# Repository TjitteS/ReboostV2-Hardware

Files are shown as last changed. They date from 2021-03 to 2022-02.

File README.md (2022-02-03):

# ReboostV2-Hardware
Hardware files for [OpenSmartEnergyConverter](https://github.com/TjitteS/OpenSmartEnergyConverter)

[Schematic](https://github.com/TjitteS/ReboostV2-Hardware/blob/main/Outputs/Reboost%20V0.2.1/Schematic%20Prints.PDF) and production files can be found in the output folder.

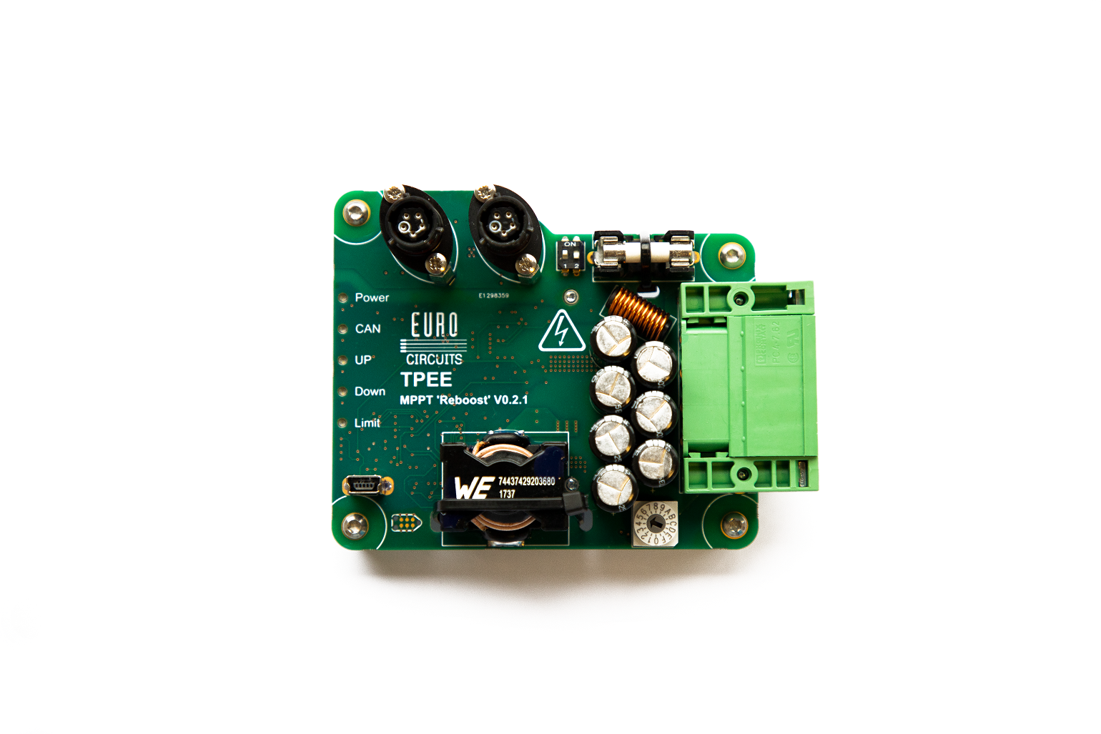
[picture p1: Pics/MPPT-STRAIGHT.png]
IMPPT


### Verison ###

The output folder contains two verison. the only major diference between the two versions is the CAN-bus connector that is used. V0.2.0 contains easy to source microfit connectors and is the recomended design.

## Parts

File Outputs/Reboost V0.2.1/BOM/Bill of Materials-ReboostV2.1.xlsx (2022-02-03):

Comment | Description | Designator | Footprint | Quantity
1nF | Capacitor, 1nF, 50V, X7R | C1_IHS, C1_ILS, C4_IHS, C4_ILS | C0603 | 4
100nF | Capacitor, 100nF, 50V, X7R | C2_IHS, C2_ILS, C3_IHS, C3_ILS, C6, C9, C13, C15, C16, C17, C18, C20, C21, C31, C39, C42, C45, C51, C54, C59, C60, C61 | C0603 | 22
2.2uF | Capacitor, 2.2uF, 16V, X5R | C5, C7, C8, C12, C14, C19, C30, C40, C52, C56, C67 | C0603 | 11
15pF | Capacitor, 15pF, 50V, C0G / NP0 | C10, C11 | C0603 | 2
100uF | Aluminum Electrolytic Capacitor, 100uF, 100V | C22, C23, C24, C25, C26, C28, C34 | WCAP-ATUL_10x20x5x0.6 | 7
100nF | Capacitor, 100nF, 100V, X7R | C27, C29, C35, C43 | C-0805 | 4
1uF | Capacitor, 1uF, 100V, X7R | C32, C33, C36, C37, C38, C44, C64 | C-1206 | 7
10uF | Capacitor, 10uF, 10V, X7R | C41, C46, C53, C58, C62, C65, C66 | C-0805 | 7
10nF | Capacitor, 10nF, 50V, X7R | C47, C55, C57 | C0603 | 3
4.7uF | Capacitor, 4.7uF, 16V, X7R | C48, C49, C50 | C-0805 | 3
SP0502BAHTG | Diode TVS Dual, Vrwm: 5.5V Vc: 8V | D1 | SOT23 | 1
SS110L | Diode Schottky, Vrrm: 100V, If: 1A, Vf: 0.9V | D2, D3 | SUB-SMA | 2
HMHA2801 | Optocoupler, Vout:80V, Iin:0.01A | D4 | FSOP4 | 1
MMSD701T1G | Diode Schottky, Vrrm: 70V, If: 0.2A, Vf: 0.5V | D5, D6, D7 | SOD123 - B | 3
SMAJ58A | Diode TVS, Vrwm: 58V, Vbr: 71.2V, Vc: 93.6V, Ippm: 4.3A | D8 | SMA | 1
Fuse Holder | Fuse, Holder, 10A, 250V, T:-40°C +85°C | F1 | Fuse5x20TH | 1
Header 1x4 | Header, Close Horizontal, 1x4, Male, 7.62mm, TH | J1 | PC 4/ 4-G-7,62 | 1
USB-B-MINI-VERT | Connector, Usb B Mini, Vertical, TH, WR-COM | J2 | USB-B-MINI-VERT | 1
CAN_BUS-Deutsch_ASL206-05SD-HE |  | J8, J9 | ASL206-05SD-HE | 2
2uH, 10A | WE-SD Rod Core Choke, 2uH, 10A | L1 | 744710210 | 1
68uH, 11.2A | WE-HCF SMT High Current Inductor, size 2920, 68uH, 11.2A, 24.42mOhm | L2 | WE-HCF_2920 | 1
150uH 0.42A | 150UH, 30%, 0.42A | L3, L4, L5 | WE-TPC 4828, MH | 3
800Ohm | WE-CNSW SMT Common Mode Line Filter, size 1812, 800Ohm, 1A, 60V | L6 | WE-CNSW_1812 | 1
90Ohm | WE-CNSW SMT Common Mode Line Filter, size 0805, 90Ohm, 0.37A, 50V | L7_VHS, L7_VLS | WE-CNSW_0805 | 2
GRN | LED, Reverse Mount, Cylindrical, Green | LED1, LED4, LED5 | WL-SMRW_1206 cylindrical_Reverse use | 3
RED | LED, Reverse Mount, Cylindrical, Red | LED2, LED3 | WL-SMRW_1206 cylindrical_Reverse use | 2
M2.5x2mm | WA-SMSI SMT Steel Spacer, M2.5 Thread Internal, OD 5.1mm, M2.5x2mm | MP1, MP2, MP3, MP4, MP5, MP6 | 9774020151 | 6
GS61008T | GAN TRANS E-MODE 100V 90A TOP SIDE COOL | Q1, Q2 | GS61008T | 2
MMBT5401LT1G | Transistor, PNP, Vce:-150V, Vcb:-160V, Veb:-5V, Ic:-0,5A, Hfe:60 to 240 | Q3 | SOT-23 | 1
330R | Resistor, 330R, 1%, 0.063W, 50V, 100PPM, 0603 | R1, R2, R3, R4, R5 | 0603 | 5
0.005R | Resistor, 0.005R, 1%, 2W, 50PPM | R6_IHS, R6_ILS | 2512-L-4T | 2
1K | Resistor, 1K, 1%, 0.063W, 50V, 100PPM, 0603 | R7_IHS, R7_ILS, R9_IHS, R9_ILS | 0603 | 4
47k | Resistor, 47K, 0.1%, 0.063W, 50V, 100PPM, 0603 | R8_IHS, R8_ILS, R10_IHS, R10_ILS, R35, R47 | 0603 | 6
10K | Resistor, 10K, 1%, 0.063W, 50V, 100PPM, 0603 | R11, R14, R15, R16, R17, R24, R32, R36, R42, R44, R45, R49_VHS, R49_VLS, R50 | 0603 | 14
120K | Resistor, 120K, 1%, 0.063W, 50V, 100PPM, 0603 | R12_VHS, R12_VLS | 0603 | 2
180K | Resistor, 180K, 1%, 0.063W, 50V, 100PPM, 0603 | R13_VHS, R13_VLS | 0603 | 2
100K | Resistor, 100K, 1%, 0.063W, 50V, 100PPM, 0603 | R18, R19, R28 | 0603 | 3
NTC-100K | NTC, 100K, 25°C, 0.5%, 0.210W, 0805 | R20, R21 | R0805 | 2
2R | Resistor, 2R, 5%, 0.1W, 75V, 200PPM, 0603 | R22, R27 | 0603 | 2
750K | Resistor, 750K, 1%, 0.063W, 50V, 100PPM, 0603 | R25, R34 | 0603 | 2
470K | Resistor, 470K, 1%, 0.063W, 50V, 100PPM, 0603 | R26 | 0603 | 1
470 | Resistor, 470, 1%, 0.063W, 50V, 100PPM, 0603 | R29 | 0603 | 1
20K | Resistor, 20K, 1%, 0.063W, 50V, 100PPM, 0603 | R30 | 0603 | 1
100R | Resistor, 100R, 1%, 0.063W, 50V, 200PPM, 0603 | R31 | 0603 | 1
130K | Resistor, 130K, 1%, 0.063W, 50V, 100PPM, 0603 | R33 | 0603 | 1
200K | Resistor, 200K, 1%, 0.063W, 50V, 100PPM, 0603, Resistor, 200K, 1%, 0.1W, 75V, 100PPM, 0603 | R37, R38, R40, R53 | 0603 | 4
0R | Resistor, 0R, 0.1%, 0.063W, 50V, 200PPM, 0603 | R39, R41 | 0603 | 2
12K | Resistor, 12K, 1%, 0.063W, 50V, 100PPM, 0603 | R48 | 0603 | 1
418127270902 | WS-DITV Small Compact THT Dip Switch, Raised Actuator, pitch 2.54mm, 2p | S1 | 418127270902 | 1
428527320916 | WS-ROTV THT Rotary Switch with Arrow Type Actuator, 10x10mm, 16 positions | S2 | 42852732091x_16p | 1
LTC6362 | Precision, Low Power Rail-to-Rail Input/Output Differential Op Amp | U1_IHS, U1_ILS | MSOP8 | 2
CP2104-F03-GM | USB to UART converter | U2 | QFN24 | 1
STM32G474 | ARM MCU, STM32 Family STM32G4 Series Microcontrollers, ARM Cortex-M4F, 32bit, 170 MHz, 512 KB | U3 | QFN48 | 1
74LVC2G08 | Dual 2-input AND gate | U4 | TSSOP8 | 1
Si8273 | 4 Amp ISOdriver with High Transient (dV/dt) Immunity | U5 | DFN-14 | 1
ISO1044 | ISO1044 Isolated CAN FD Transceiver in Small Package | U6 | SO-8 | 1
LM5165XDRCT | Buck Vreg 150mA 5Vout 5-65Vin | U7 | PWSON10 | 1
LTC3639EMSE | High Efficiency, 150V 100mA Synchronous Step-Down Regulator | U8 | MSE1612 | 1
LM5165YDRCT | Buck Vreg 150mA 3V3 out 5-65Vin | U9 | PWSON10 | 1
LP2985AIM5-3.3 | LDO, 0.3VDO, 3.3V, 0.15A, 1% | U10 | SOT-23-5 | 1
TPS7A2501 | TPS7A25 300-mA,18-V, Ultra-LowIQ, Low-DropoutLinearVoltageRegulatorWith Power-Good | U11 | WSON-6 | 1
16MHz | CRYSTAL, 16MHz,18PF CL, 3.2X2.5MM SMT | X1 | 7M | 1

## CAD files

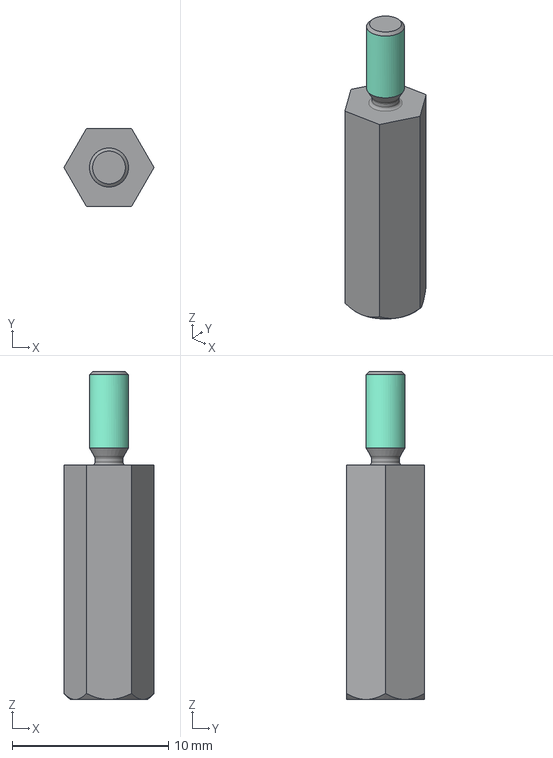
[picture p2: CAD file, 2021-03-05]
Download_STEP_971150151 (rev1).stp
5.77 x 5.00 x 21.0 mm

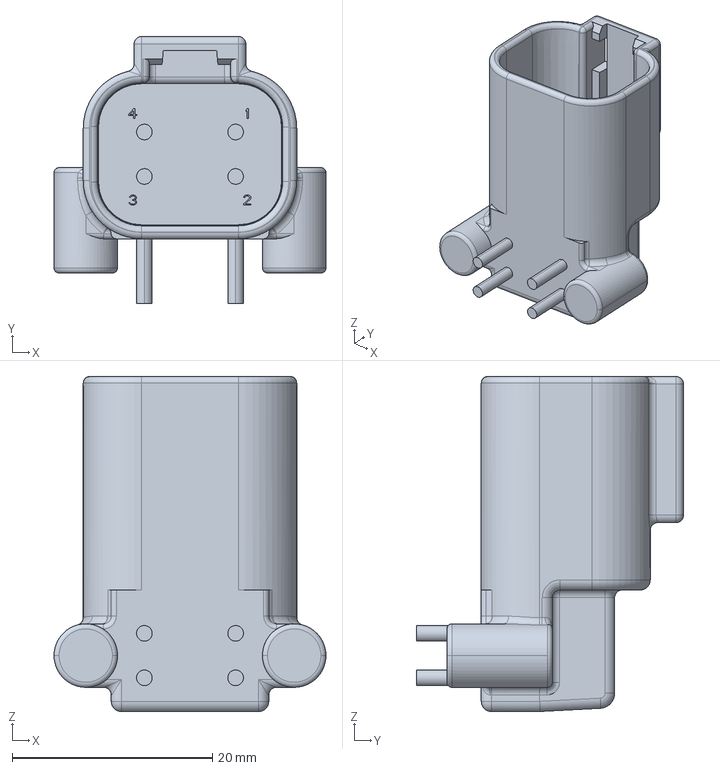
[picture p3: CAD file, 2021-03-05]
c-dtf13-4p-g003-a-3d.stp
27.2 x 26.7 x 33.5 mm

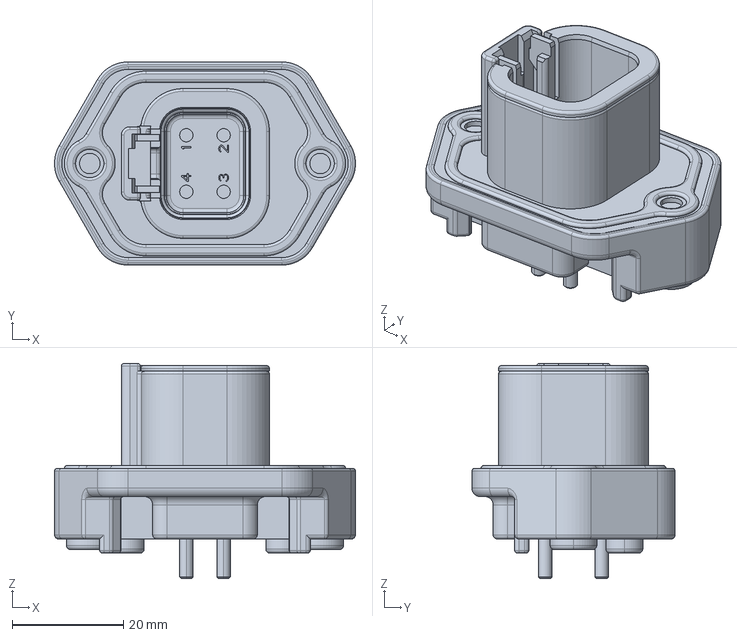
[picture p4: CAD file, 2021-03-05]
c-dtp15-4p-99-3d.stp
54.1 x 36.5 x 38.7 mm

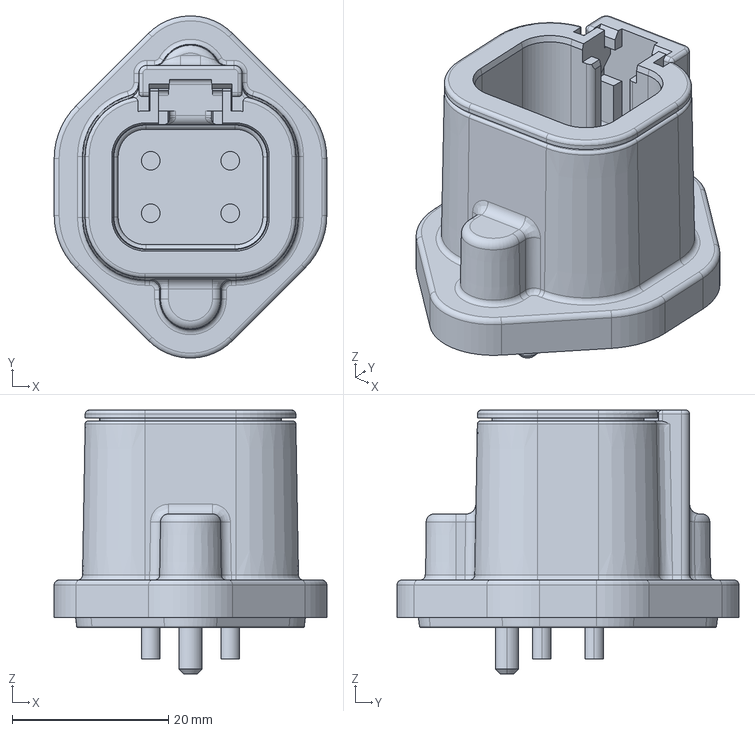
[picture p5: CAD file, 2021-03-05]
c-dtp10-4p-b-3d.stp
34.8 x 43.7 x 33.7 mm

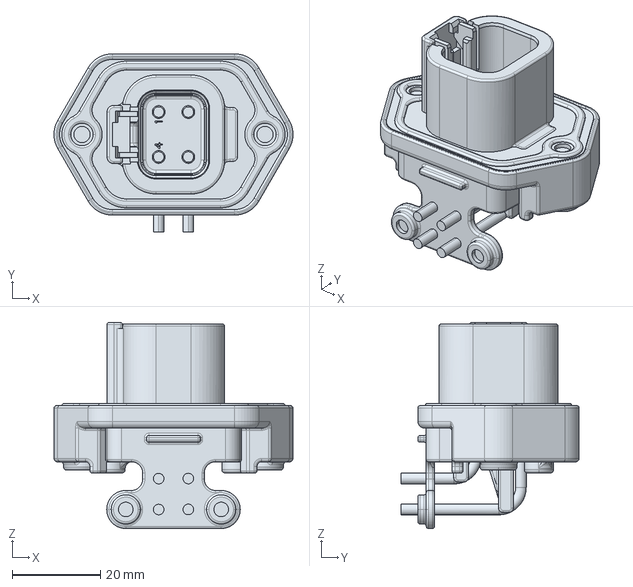
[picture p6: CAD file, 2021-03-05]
c-dtp13-4p-b-3d.stp
54.1 x 40.4 x 46.7 mm

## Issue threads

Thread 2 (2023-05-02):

Input capacitor current rating

TjitteS, 2023-05-02:
As pointed out by Reddit user splynk13 the current rating of the input capacitors is too low.
With 80V, 68uH inductance, 100 khz switching frequency and 50% dutycylce, the RMS ripple current through the input capacitor is 0.849A (worst case). The capacitors in the BOM (WCAP-ATUL, mpn 860040875005) are rated for 0.8A.

Suggested replacement is part EEU-FR2A101

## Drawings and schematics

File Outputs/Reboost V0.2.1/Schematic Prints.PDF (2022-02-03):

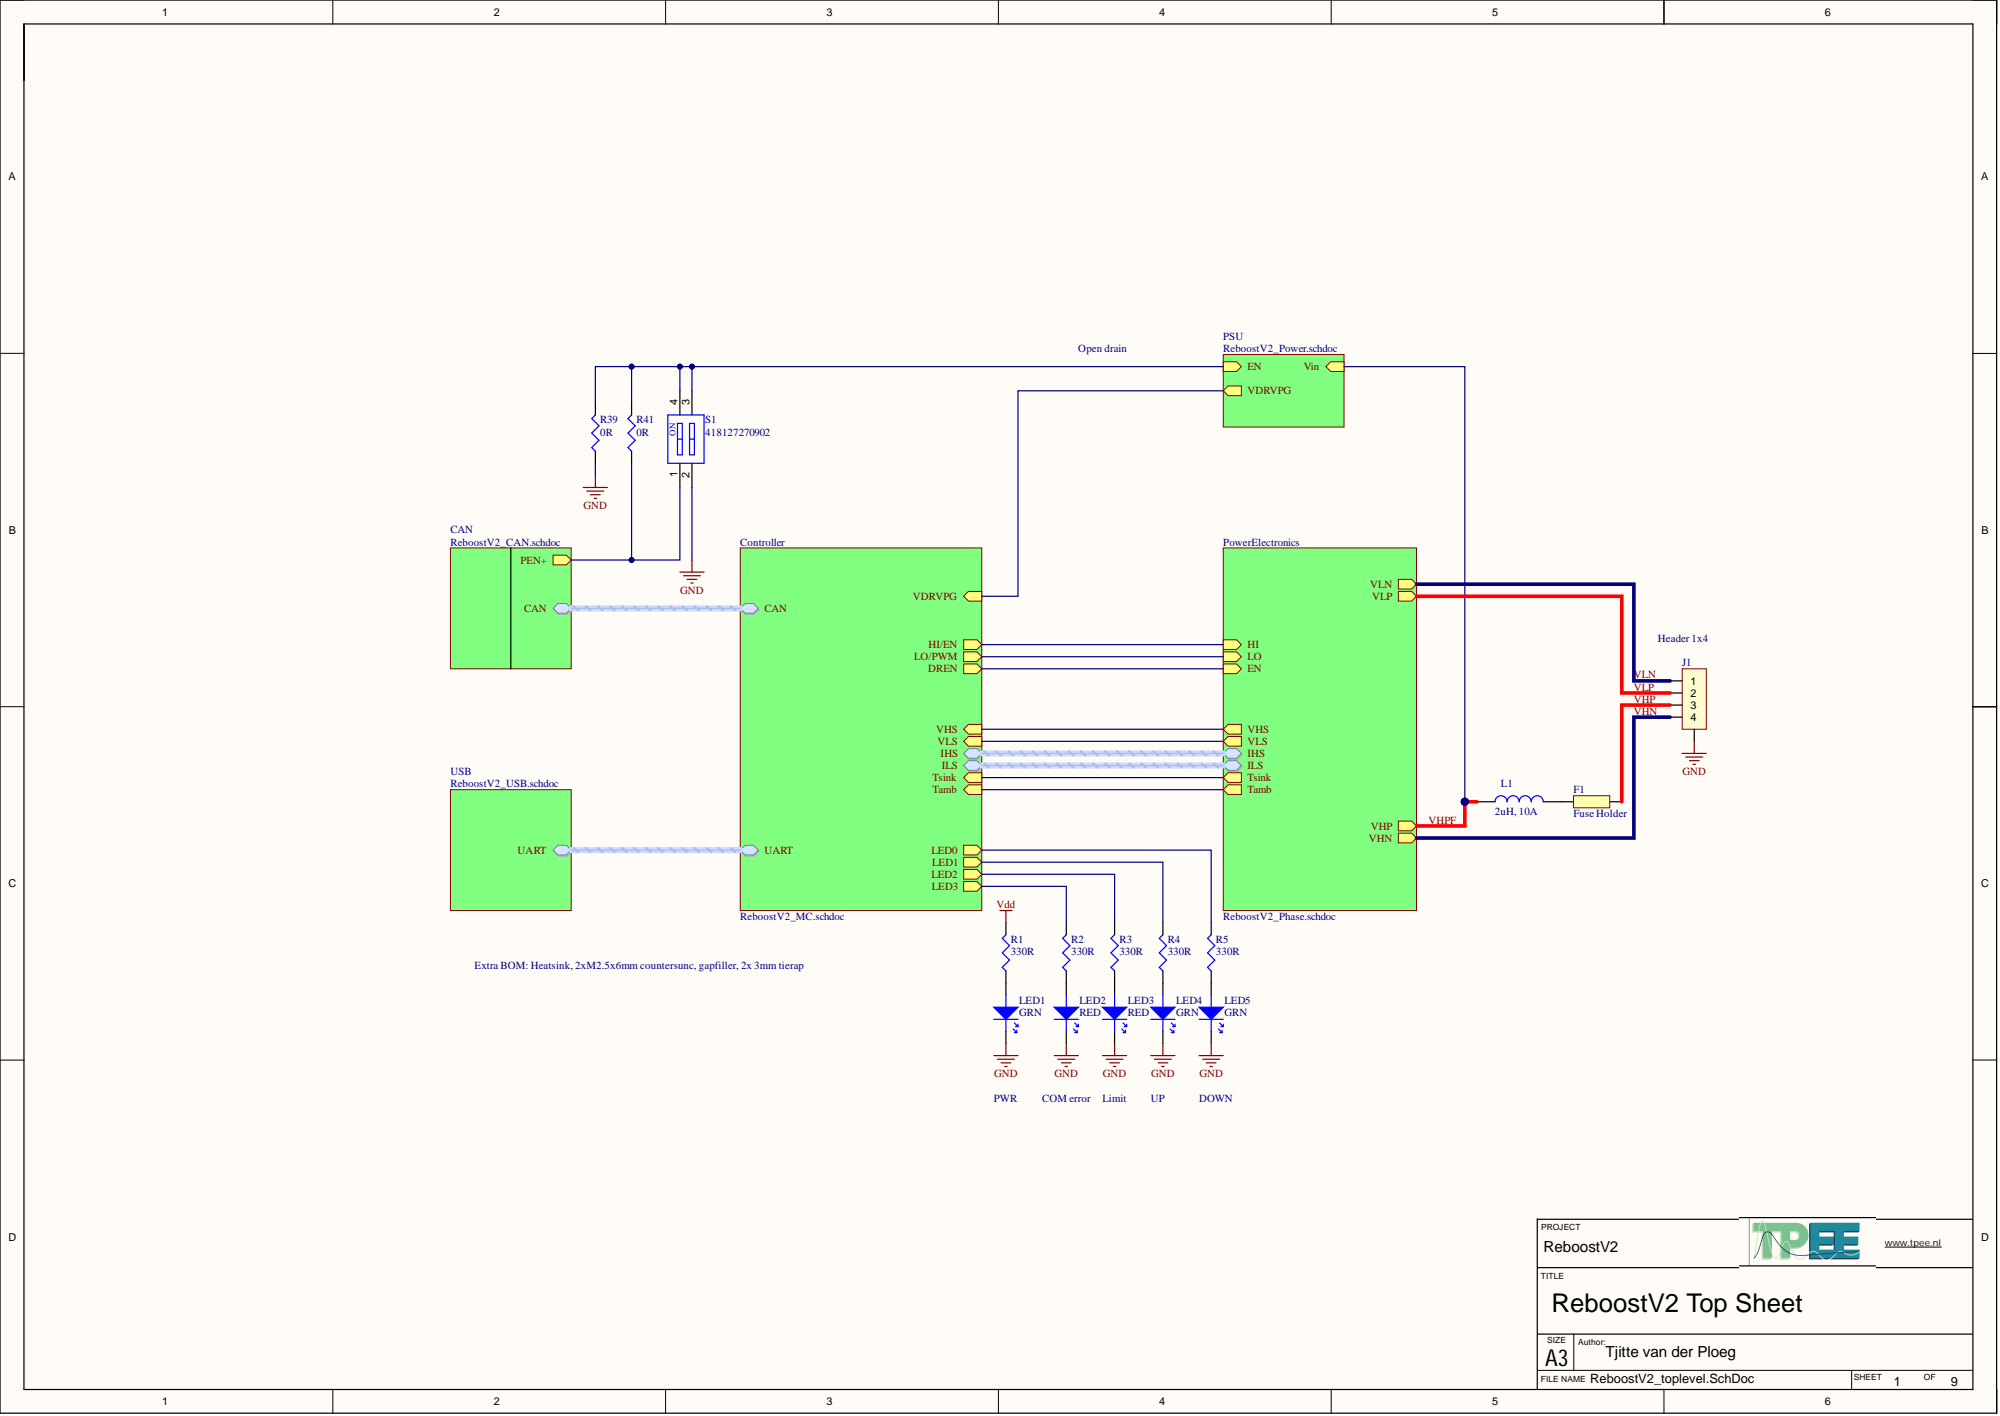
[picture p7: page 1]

VLN
VLP
VHP

Extra BOM: Heatsink, 2xM2.5x6mm countersunc, gapfiller, 2x 3mm tierap

SIZE A3 | Author: Tjitte van der Ploeg

FILE NAME ReboostV2_toplevel.SchDoc | SHEET 1 OF

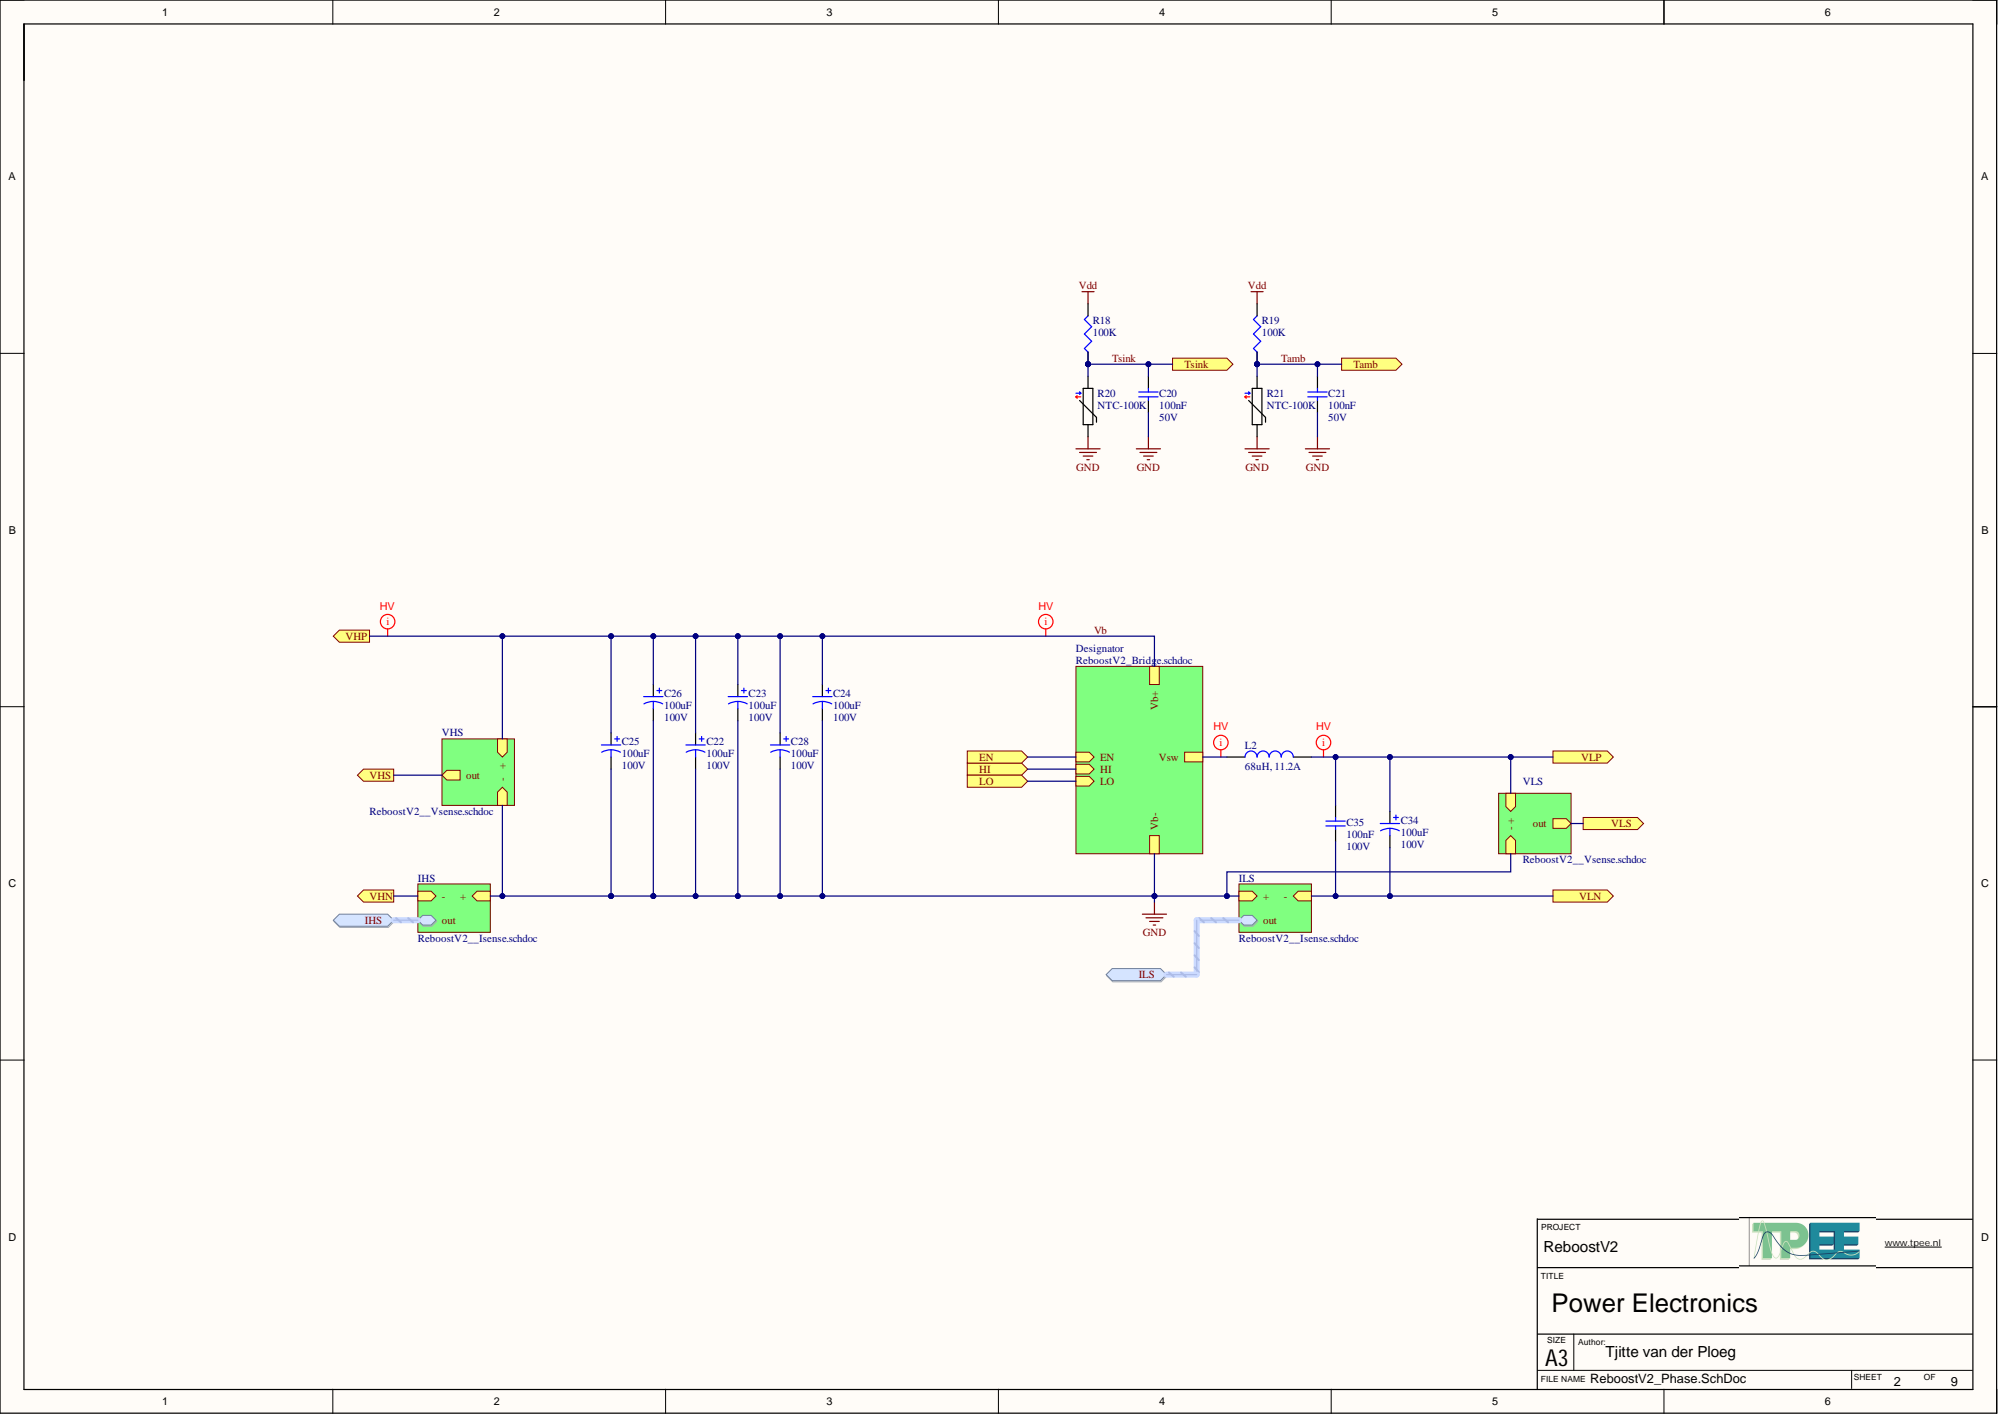
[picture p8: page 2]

ILS

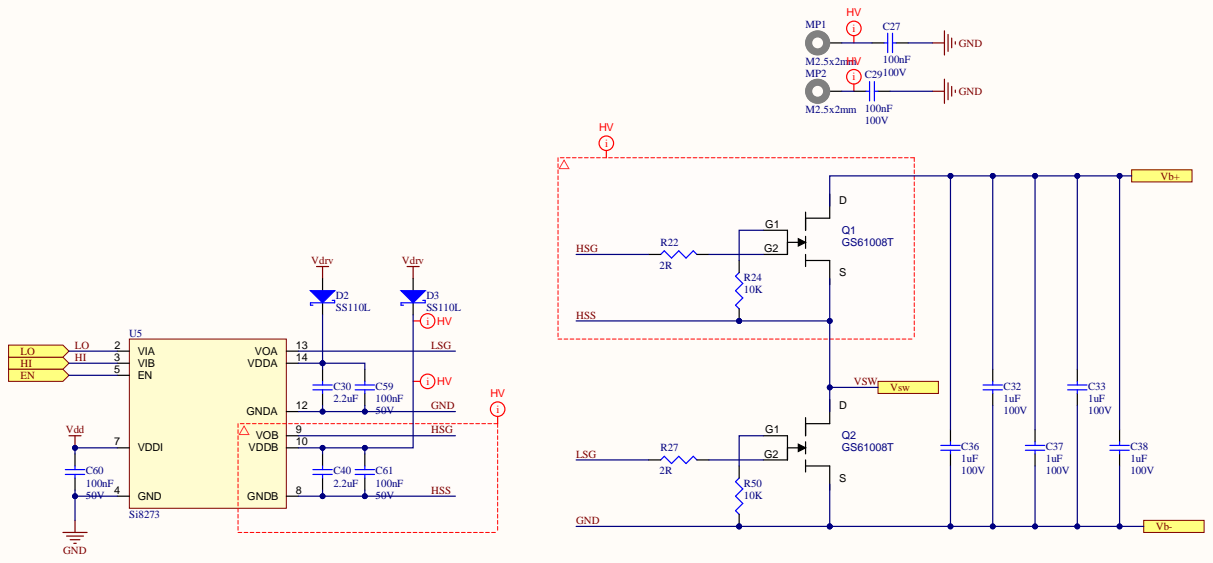
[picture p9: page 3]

SIZE | Auth or: Tj i t te van der Ploeg

E ReboostV2_B ridge.SchDoc FILE NAM | SHEET O F

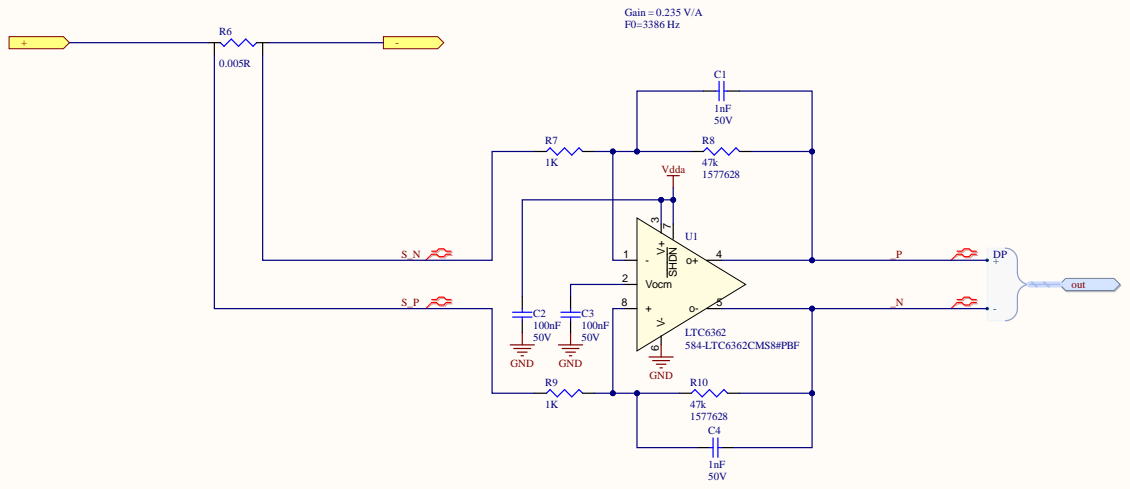
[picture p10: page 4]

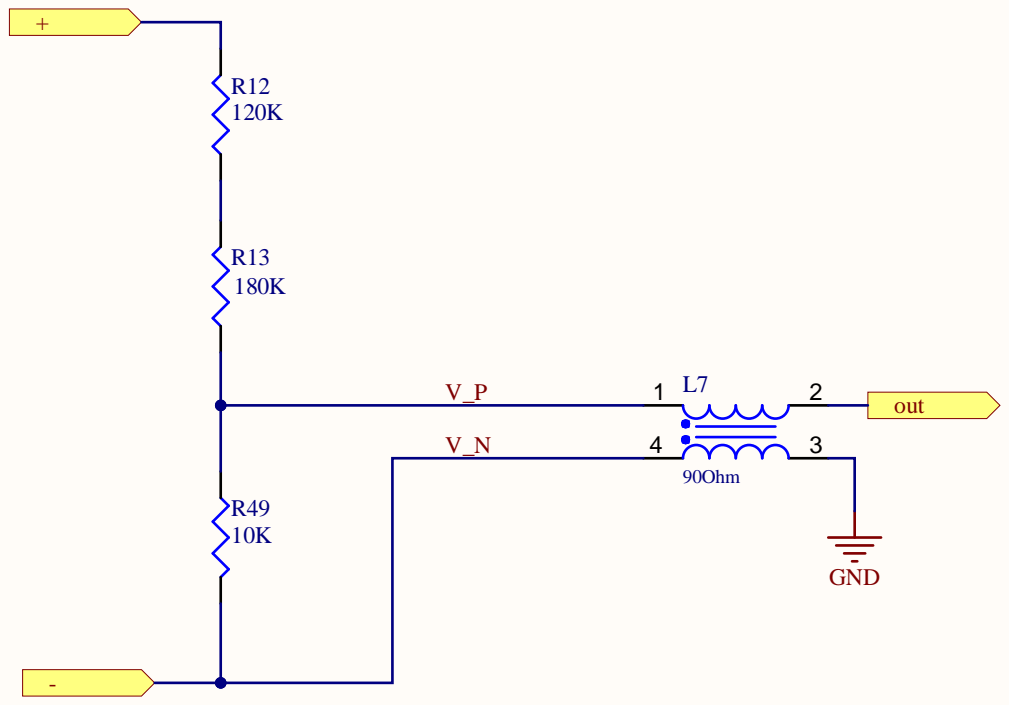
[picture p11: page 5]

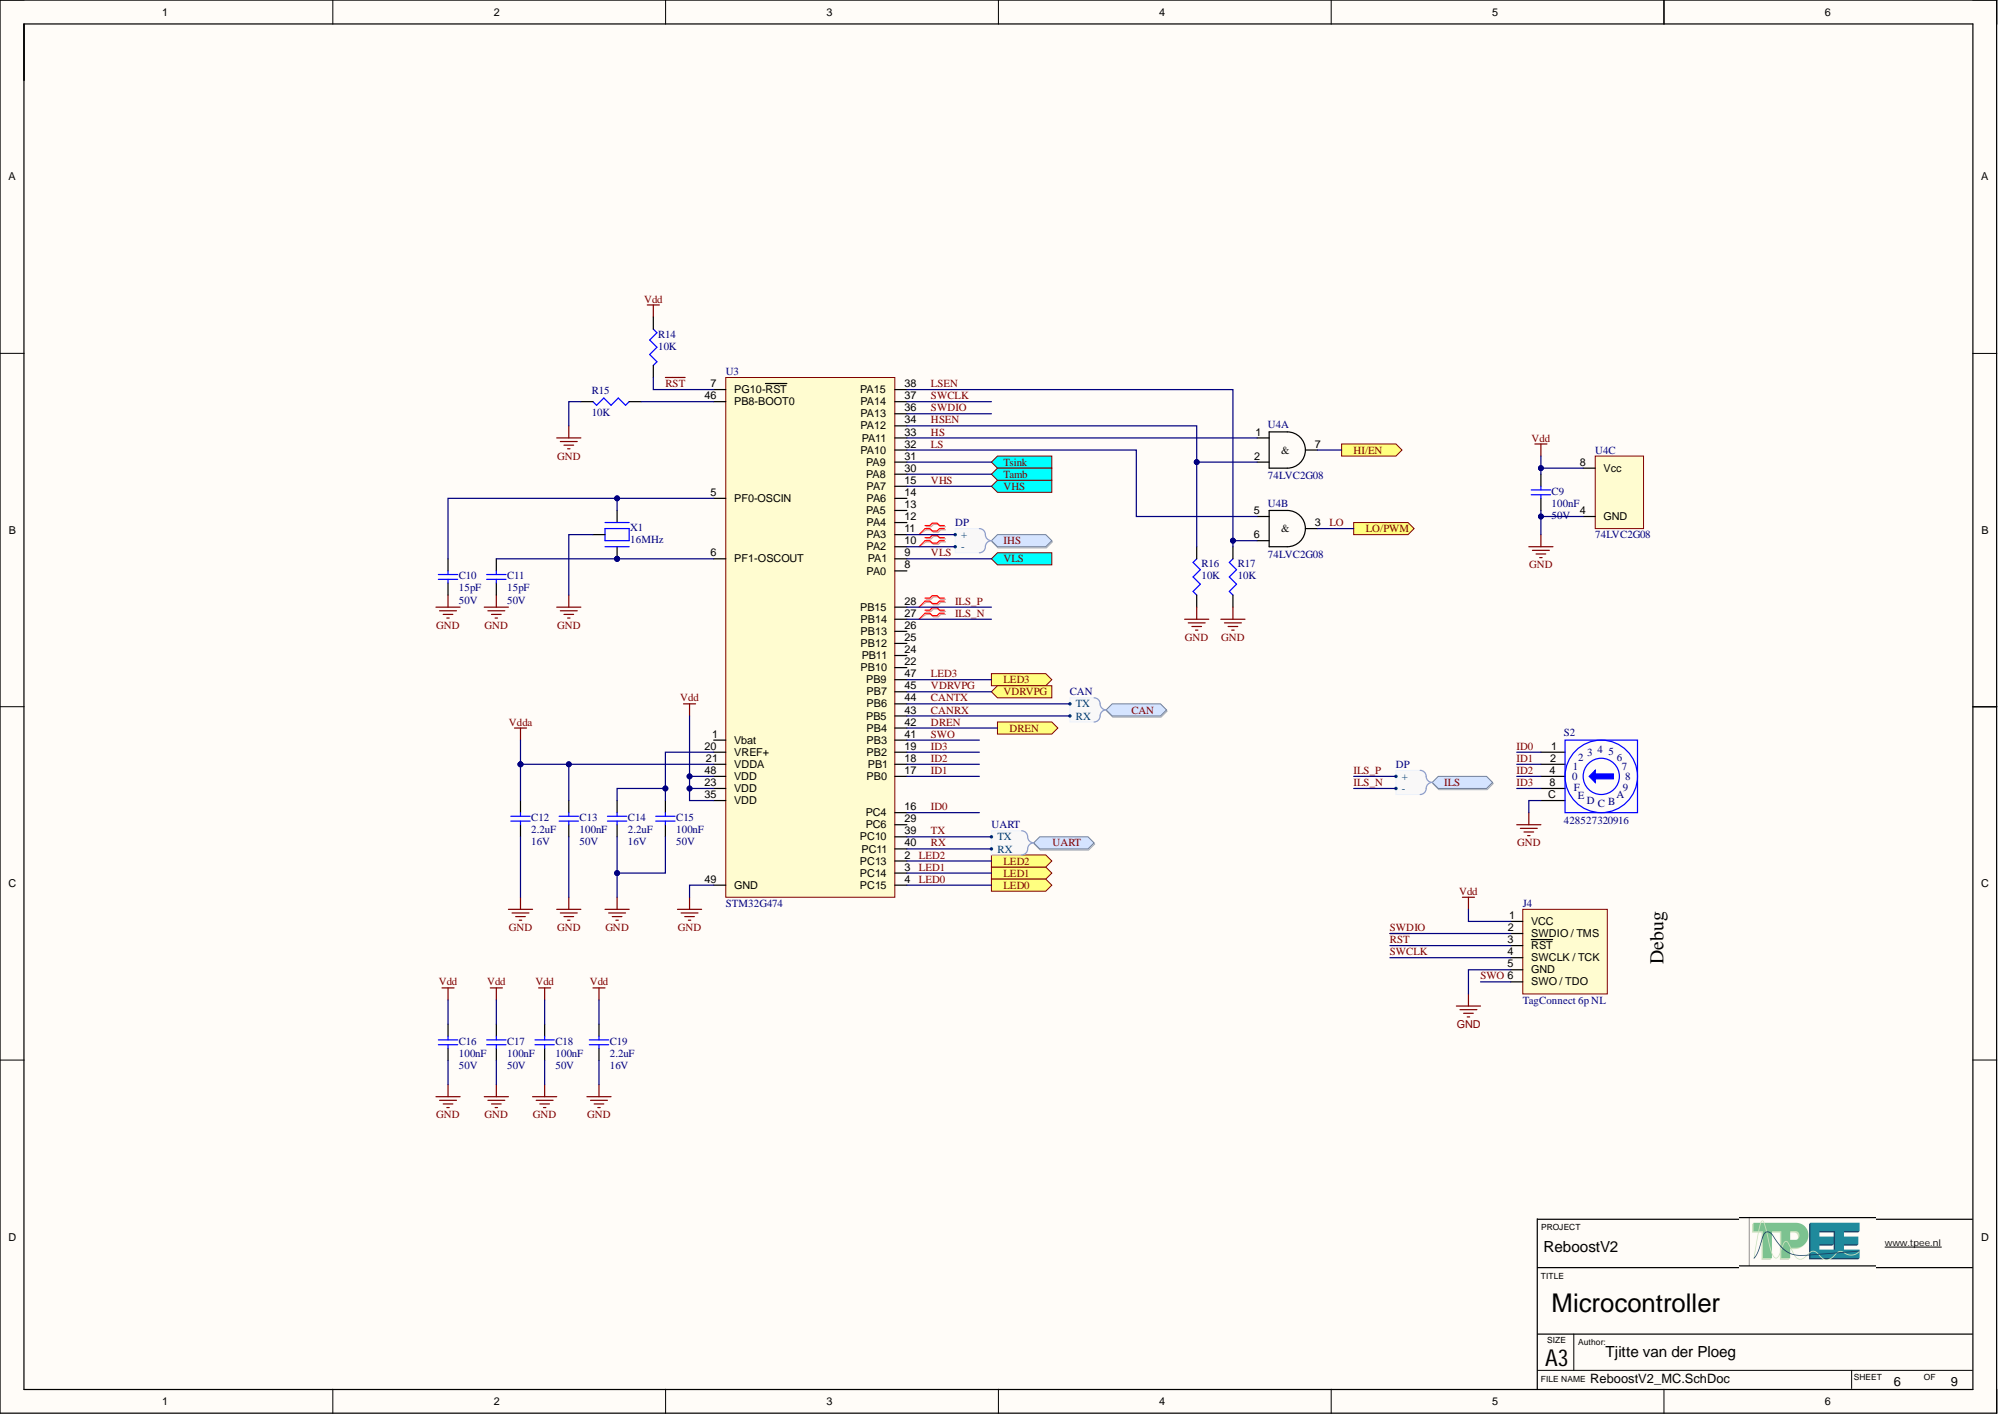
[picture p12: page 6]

T s i n k Tamb V H S V H S

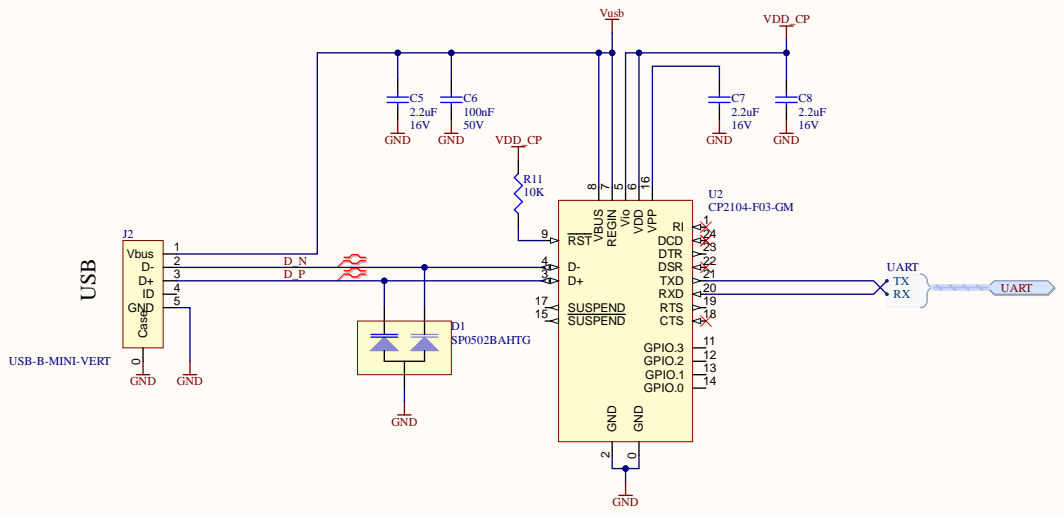
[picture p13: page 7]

3 D _P | 3

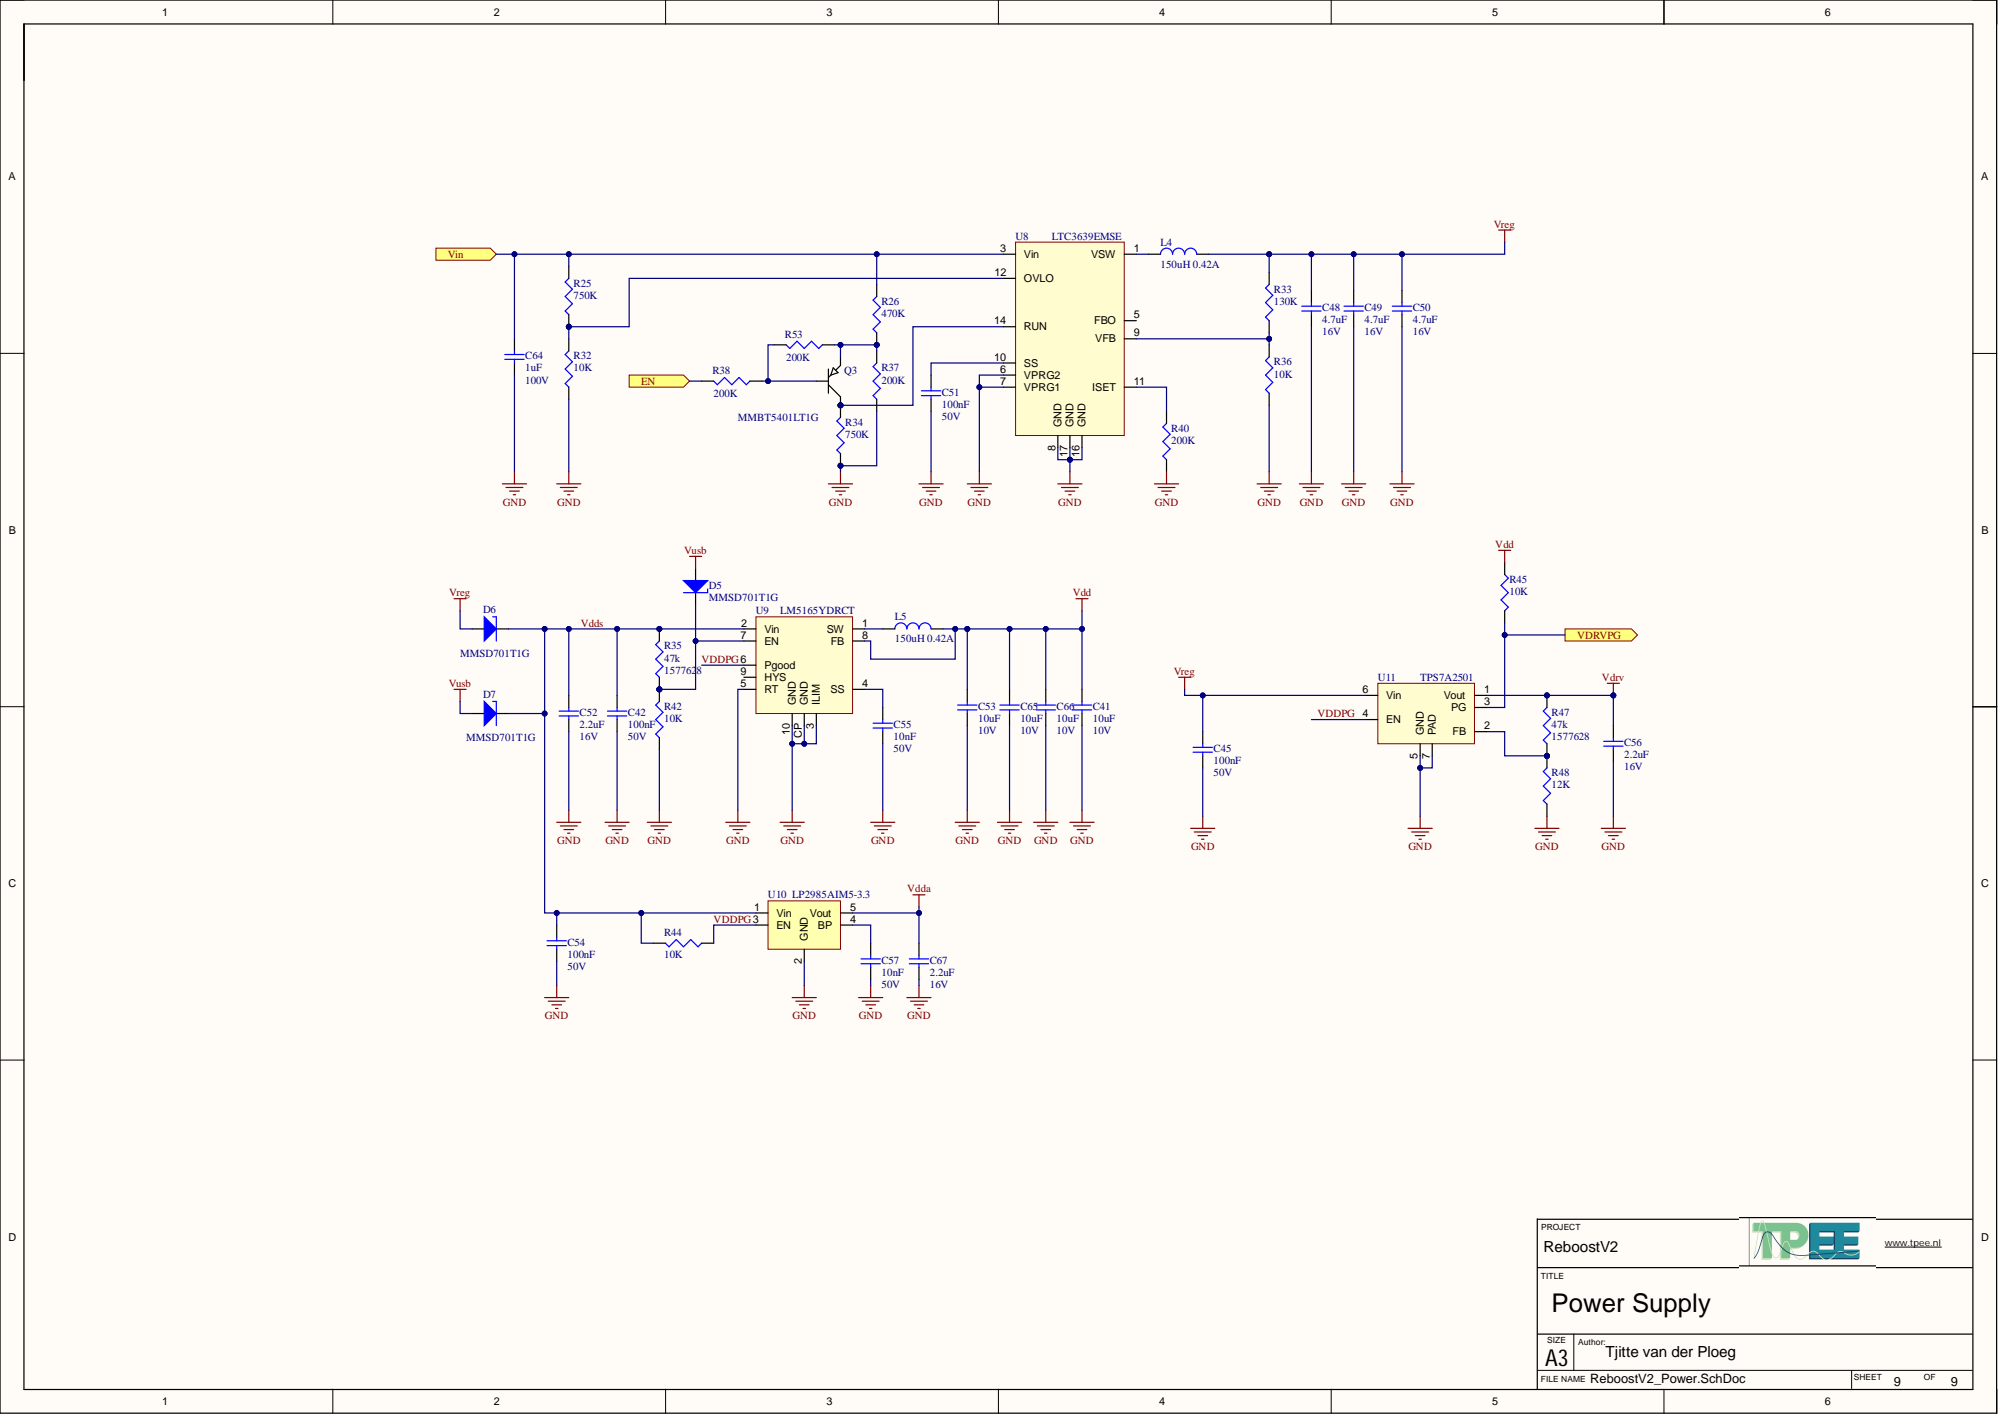
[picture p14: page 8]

OVLO 12

R26 470K | RUN 14

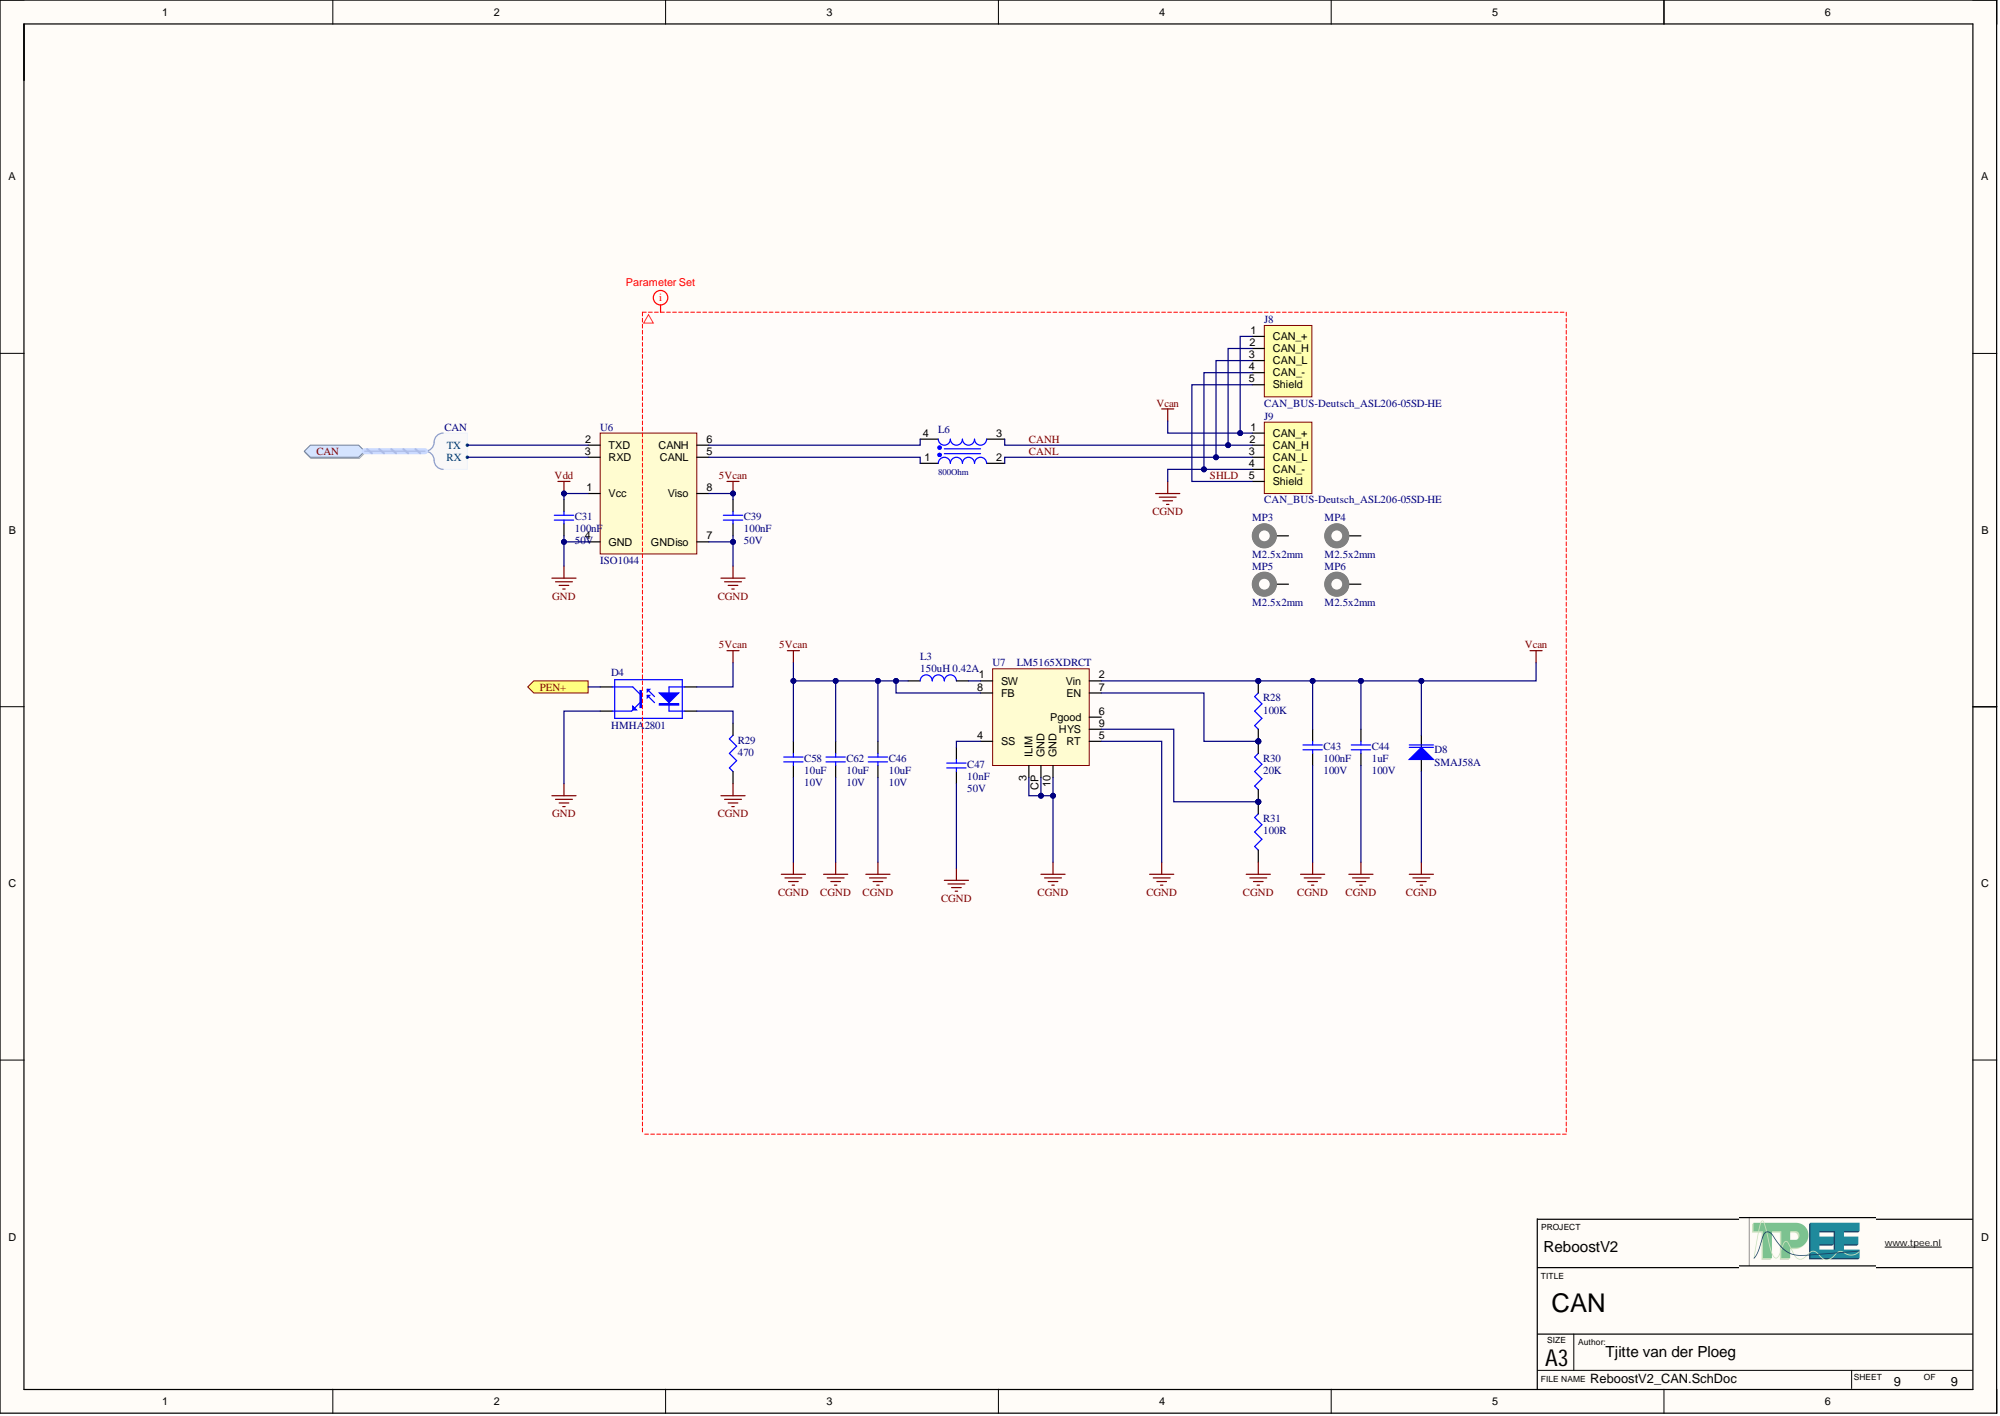
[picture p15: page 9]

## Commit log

2021-03-05 Hardware V2.1
    [Download_STEP_971150151 (rev1).stp, ReboostV2_Bridge.SchDoc, ReboostV2_CAN.SchDoc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]
2022-02-02 final chances
    [ReboostV2__Isense.SchDoc]
2022-02-02 Removed files.
    [Pick Place for ReboostV2.1.csv, Reboostv031.xlsx, Reboostv21 BOM.xlsx]
2022-02-03 Added project outputs
    [Bill of Materials-ReboostV2.1.xlsx, Copy of Bill of Materials-ReboostV2.xlsx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]
